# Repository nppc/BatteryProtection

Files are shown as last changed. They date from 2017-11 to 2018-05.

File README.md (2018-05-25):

# Protection circuit for 5S LiIon Battery
The battery is used in mine grass trimmer.

The protection circuit monitoring battery voltage and turns load off if battery gets empty.

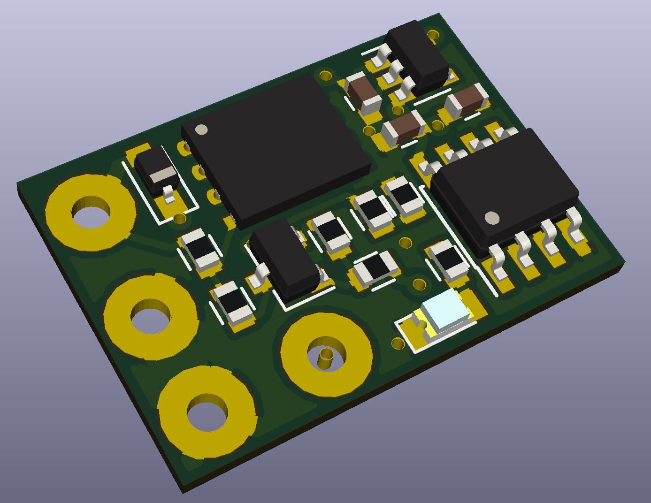
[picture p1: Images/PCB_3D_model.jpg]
3D board


Maximum input voltage is 23V.

Low voltage threshold is 15v.

Please make sure, that if your internal reference is 1.1v, then R3 is 68K, not 12K. 12K is for 5V reference.

## Components placement
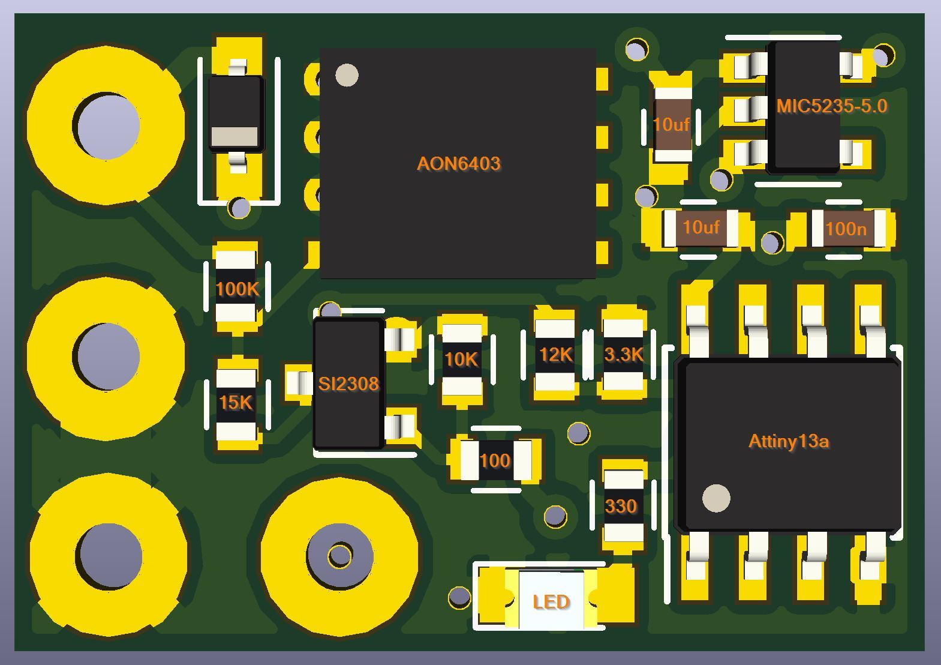
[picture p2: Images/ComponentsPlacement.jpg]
Components placement


## Indication
When led blinks with long pauses, then battery is not empty.

When led is constantly on then battery is empty, load is disconnected. To reset the board you need to disconnect the battery.

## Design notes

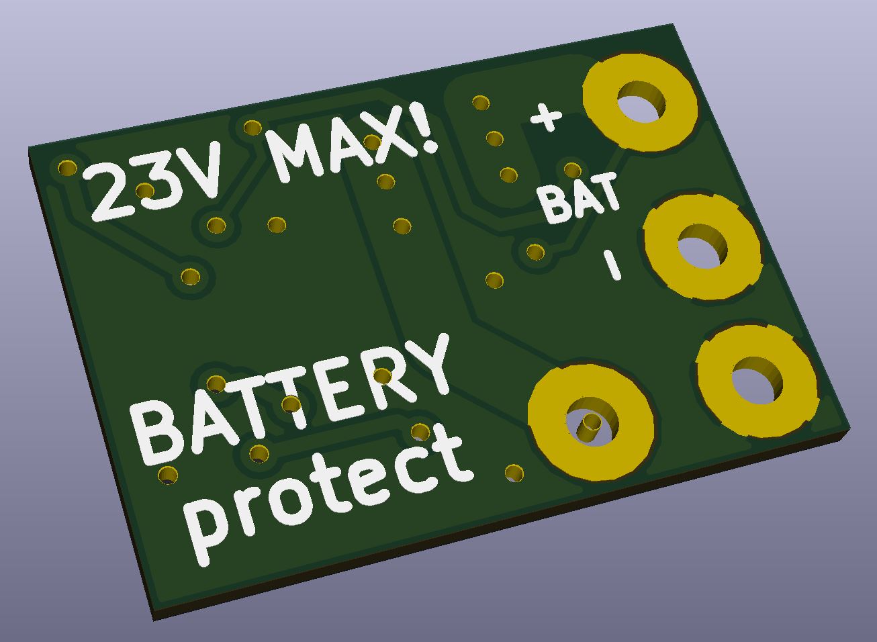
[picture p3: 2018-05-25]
Images/PCB_3D_model_bot.jpg

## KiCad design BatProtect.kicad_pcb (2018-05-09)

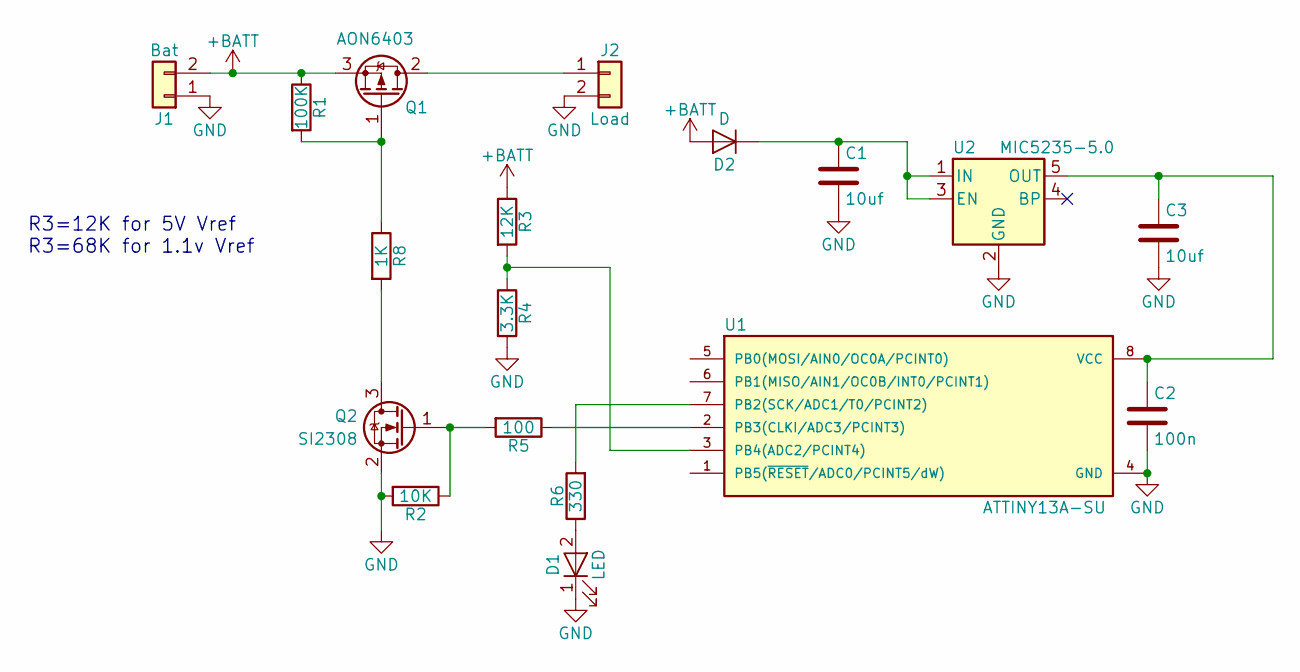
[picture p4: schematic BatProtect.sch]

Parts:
C1, C3: 10uf; C_0603
C2: 100n; C_0603
D1: LED; LED_0805
D2: D; D_SOD-323_HandSoldering
J1: Bat; Connector_2x5mm_1.5Drill
J2: Load; Connector_2x5mm_1.5Drill
Q1: AON6403; DFN-8-1EP_6x5mm
Q2: SI2308; SOT-23
R1: 100K; R_0603
R2: 10K; R_0603
R3: 12K; R_0603
R4: 3.3K; R_0603
R5: 100; R_0603
R6: 330; R_0603
R8: 1K; R_0603
U1: ATTINY13A-SU; SOIC-8_3.9x4.9mm_Pitch1.27mm
U2: MIC5235-5.0; SOT-23-5

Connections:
+BATT: D2.2 (A), J1.2, Q1.3 (S), R1.1, R3.1
GND: C1.2, C2.2, C3.2, D1.1 (K), J1.1, J2.2, Q2.2 (S), R2.2, R4.2, U1.4 (GND), U2.2 (GND)
unnamed: C1.1, D2.1 (K), U2.1 (IN), U2.3 (EN)
unnamed: C2.1, C3.1, U1.8 (VCC), U2.5 (OUT)
unnamed: D1.2 (A), R6.1
unnamed: J2.1, Q1.2 (D)
unnamed: Q1.1 (G), R1.2, R8.1
unnamed: Q2.1 (G), R2.1, R5.2
unnamed: Q2.3 (D), R8.2
unnamed: R3.2, R4.1, U1.3 (PB4(ADC2/PCINT4))
unnamed: R5.1, U1.2 (PB3(CLKI/ADC3/PCINT3))
unnamed: R6.2, U1.7 (PB2(SCK/ADC1/T0/PCINT2))

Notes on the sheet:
R3=12K for 5V Vref R3=68K for 1.1v Vref

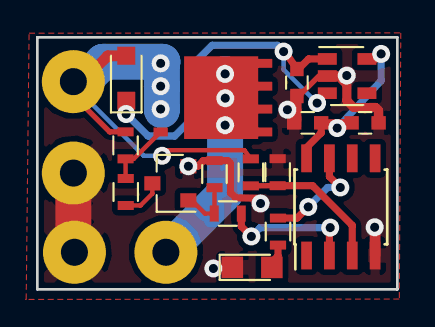
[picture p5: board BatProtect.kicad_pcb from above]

Board: 2 copper layers, 20.0 x 14.0 mm, 18 parts (0 on the bottom side), 12 nets.

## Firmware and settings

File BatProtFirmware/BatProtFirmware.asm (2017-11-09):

; * Author of BatProtFirmware is Pavel Palonen
; *
; * BatProtFirmware is free software: you can redistribute it and/or modify
; * it under the terms of the GNU General Public License as published by
; * the Free Software Foundation, either version 3 of the License, or
; * (at your option) any later version.
; *
; * BatProtFirmware is distributed WITHOUT ANY WARRANTY; without even the implied warranty of
; * MERCHANTABILITY or FITNESS FOR A PARTICULAR PURPOSE.  See the
; * GNU General Public License for more details.
; * this text shall be included in all
; * copies or substantial portions of the Software.
; *
; * See <http://www.gnu.org/licenses/>.

.include "tn13Adef.inc"


;---- END of configurable defines ----

; Predefined configurable parameters
.EQU	LOW_BAT_VOLTAGE		= 150	; means 15.0 volts
.EQU	BAT_CORRECTION		= 0		; Signed value for correction voltage readings (for debug use 1)

; END OF predefined configurable parameters


; If you did not changed hardware, then you don't need to change this...
;.EQU	VOLT_DIV_CONST		= 141		; 5V vref (12K/3.3K)
.EQU	VOLT_DIV_CONST		= 138		; 1.1V vref (68K/3.3K)
										; To get this number use formula (for 23v max): 
										; 4095/(Vmax*10)*8, where Vmax=(R1+R2)*Vref/R2
										; Vref=5v 
										; and resistor values is from divider (12K/3.3K)
										; Vmax=(12+3.3)*5/3.3=23.18
										; 4095/(23.18*10)*8=141
										
.EQU	ENLDO_PIN	= PB0	; Pin for device Configuration
.EQU	LED_PIN		= PB2	; Vertical sync pin
.EQU	CNTRL_PIN	= PB3	; Mosfet Control pin
.EQU	VBAT_PIN	= PB4	; Resistor divider (10K/3K) for voltage measurement (21v max)

.def	z0			=	r0
.def	z1			=	r1
.def	r_sreg		=	r2	; Store SREG register in interrupts
.def	tmp			=	r16
.def	tmp1		=	r17
.def	tmp2		=	r3
.def	itmp		=	r18	; variables to use in interrupts
.def	itmp1		=	r19	; variables to use in interrupts
.def	itmp2		=	r4	; variables to use in interrupts
.def	voltage		=	r20	; voltage in volts * 10
.def	lowbat_cntr	=	r21	; counter for blinking voltage when it gets low
.def	adc_cntr	=	r23	; counter for ADC readings
; Variables XL:XH, YL:YH, ZL:ZH are used in interrupts, so only use them in main code when interrupts are disabled
.def	adc_sumL	=	r8	; accumulated readings of ADC (sum of 64 values)
.def	adc_sumH	=	r9	; accumulated readings of ADC (sum of 64 values)

.DSEG
.ORG 0x60

.CSEG
.ORG 0
		rjmp RESET ; Reset Handler
		reti	;rjmp EXT_INT0 ; IRQ0 Handler
		reti	;rjmp PCINT_int ; PCINT0 Handler
		reti	;rjmp TIM0_OVF ; Timer0 Overflow Handler
		reti	;rjmp EE_RDY ; EEPROM Ready Handler
		reti	;rjmp ANA_COMP ; Analog Comparator Handler
		reti	;rjmp TIM0_COMPA ; Timer0 CompareA Handler
		reti	;rjmp TIM0_COMPB ; Timer0 CompareB Handler
		reti	;rjmp WATCHDOG
		reti	;rjmp ADC ; ADC Conversion Handler

.include "adc.inc"

RESET:
		ldi tmp, low(RAMEND); Main program start
		out SPL,tmp ; Set Stack Pointer to top of RAM
		
		;init variables
		clr z0
		clr z1
		inc z1
		;clr adc_cntr		; couter for ADC readings. No need to initialize. Anyway we give some time for ADC to initialize all variables and states
		
		; change speed (ensure 9.6 mhz ossc)
;		ldi tmp, 1<<CLKPCE
;		ldi tmp1, 1<<CLKPS2	; 16 divisor
;		out CLKPR, tmp		; enable clock change
;		out CLKPR, tmp1		; prescaler 16
		
		; Configure Video pin as OUTPUT (LOW)
		sbi	PORTB, ENLDO_PIN
		sbi	DDRB, ENLDO_PIN
		sbi	DDRB, LED_PIN
		sbi	DDRB, CNTRL_PIN
		; Enable pullup on Configure Pin. We will enter configure mode if this pin will go LOW (by PCINT interrupt)
		sbi	PORTB, LED_PIN ; LED ON indicating, that power to the MCU is ok.
		cbi	PORTB, CNTRL_PIN ; MOSFET OFF
		
		; turn off digital circuity in analog pin
		sbi DIDR0, VBAT_PIN
		
		; Configure ADC
		; 5Vref, ADC channel, 10bit ADC result
		;ldi tmp, 0<<REFS0 | 0<<MUX0 | 1<<MUX1	; 5V vref
		ldi tmp, 1<<REFS0 | 0<<MUX0 | 1<<MUX1	; 1.1V vref
		out ADMUX, tmp
		; normal mode (single conversion mode), 16 prescaler (about 75khz at 9.6/8mhz ossc).
		ldi tmp, 1<<ADEN | 1<<ADSC | 1<<ADPS2 | 0<<ADPS1 | 0<<ADPS0
		out ADCSRA, tmp


		; Wait for voltage stabilizing and ADC warmup
		ldi lowbat_cntr, 254	; We want to start this counter to make a delay for voltage stabilizing
strt_wt:rcall ReadVoltage
		dec lowbat_cntr
		brne strt_wt	; read ADC 255 times
		; now our voltage and voltage_min is messed. Lets reset at least voltage_min.
		
		ldi tmp, 1<<SM1 | 0<<SM0 | 1<<SE	; power down sleep mode enable
		out MCUCR, tmp
		
		rcall WDT_Start	; start timer
		
		sei ; Enable interrupts
		
		sbi	PORTB, CNTRL_PIN	; turn on mosfet

		cbi	PORTB, LED_PIN	; turn off LED
		
main_loop:
		sleep
		; read ADSC bit to see if conversion finished
		sbi	PORTB, LED_PIN	; turn off LED
		rcall ReadVoltage
		cbi	PORTB, LED_PIN	; turn off LED
		;compare voltage to minimum voltage
		cpi voltage, LOW_BAT_VOLTAGE
		brsh main_loop	; voltage is ok
		; voltage is critical
		; we need to have critical voltage for at least two seconds.
		sbi	PORTB, LED_PIN	; indicate that critical issue is started
		sleep	; wait for some time
		cbi	PORTB, LED_PIN	; indicate that critical issue is started
		; read voltage agian
		rcall ReadVoltage
		cpi voltage, LOW_BAT_VOLTAGE
		brsh main_loop	; voltage is good
		; low bat is confirmed
		cbi	PORTB, CNTRL_PIN	; turn off mosfet
		; indicate that battery is disconnected by flashing the LED with interval 0.5 sec
		rcall WDT_Start05s	; watchdog interval 0.5sec
		ldi lowbat_cntr, 40	; We want to start this counter to make a delay for voltage stabilizing
lowbatwarn:
		cbi	PORTB, LED_PIN
		sleep
		sbi	PORTB, LED_PIN
		sleep
		dec lowbat_cntr
		brne lowbatwarn
	
		; turn off everything
		;cbi	PORTB, ENLDO_PIN	; turn of MCU (kill me)
		cli
		;cbi	PORTB, LED_PIN
		; freeze
L1:		;sleep
		rjmp L1
		
WDT_Start05s:
		ldi   tmp1, (0<<WDE) | (1<<WDTIE) | (0<<WDP3) | (1<<WDP2) | (0<<WDP1) | (1<<WDP0)		; 0.5s
		rjmp WDT_Start1
WDT_Start:	; with interrupt behaviour
		ldi   tmp1, (0<<WDE) | (1<<WDTIE) | (0<<WDP3) | (1<<WDP2) | (1<<WDP1) | (1<<WDP0)		; 2s
WDT_Start1:
		wdr		; Reset Watchdog Timer
		; Start timed sequence
		in    tmp, WDTCR
		ori   tmp, (1<<WDCE) | (1<<WDE)
		out   WDTCR, tmp
		; --  Got four cycles to set the new values from here -
		out   WDTCR, tmp1
		
		ret

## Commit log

2017-10-18 Adjust wierd problem in schematic and add firmware
    [BatProtect.kicad_pcb, BatProtect.sch]
2017-10-18 Correct another wierd error
    [BatProtect.kicad_pcb]
2017-10-19 Some fixes and logic changes
    [BatProtFirmware.asm]
2017-10-19 Again wierd bug in the schematic fixed
    [BatProtect.sch]
2017-10-31 Adjust a bit schematic. Correct resistor divider
    [BatProtect.kicad_pcb, BatProtect.sch]
2017-11-09 ADC Vref changed from 5V to 1.1V
    [BatProtect.sch]
2018-05-09 Changed the mosfet to better one. PCB redesign
    [BatProtect.kicad_pcb, BatProtect.sch]
2018-05-25 Adjust resistor value to get safe Vgs
    [BatProtect.sch]
